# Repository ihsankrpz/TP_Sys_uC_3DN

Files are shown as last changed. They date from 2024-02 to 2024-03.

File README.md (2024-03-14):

# TP_Sys_uC_3DN

This project is an learning project of using STM32L021K4T6 with KiCAD.
There is three part : 
	- Datasheets : All datashetts needed for the project
	- Firmware : STM32 firmware using STM32CubeIDE
	- Hardware : Conception with KiCAD.

# Hardware

#STM32L021K4T6
PB9 pin is connected to reset. L1,C4 and C5 is used to filter power supply.

#POWER SUPPLY
For the power supply, the datasheet indicated that all C's need to be more than 0.47uF.

#DAC
For DAC, in page 25, datasheet of MCP4801 indicates that C9 has to be 100n and C10 10u. 
not(CS) is the Chip Select input pin, which requires an active low to enable serial clock and data functions. 
not(LDAC) (latch DAC synchronization input) pin is used to transfer the input latch register to the DAC register (output latches, VOUT). 
When this pin is low, VOUT is updated with input register content. 
This pin can be tied to low (VSS) if the VOUT update is desired at the rising edge of the CS pin. 
This pin can be driven by an external control device such as an MCU I/O pin. 
MISO pin of SDI not used because STM32 is used Transmit only.

# Firmware

#LL drivers
Using LL drivers instead of using HAL drivers allows to use low-level registers to have beter optimisation.
LL drivers are specific to uC and HAL drivers are more portable.

#__STATIC_INLINE
__STATIC_INLINE is used to declare a function statically and the compiler will generate function only where necessary.

#Led_Timer
We have 32Mhz clock and we need to scale the timer at 1kHz clock. We choose PSC + ARR  = 32000.

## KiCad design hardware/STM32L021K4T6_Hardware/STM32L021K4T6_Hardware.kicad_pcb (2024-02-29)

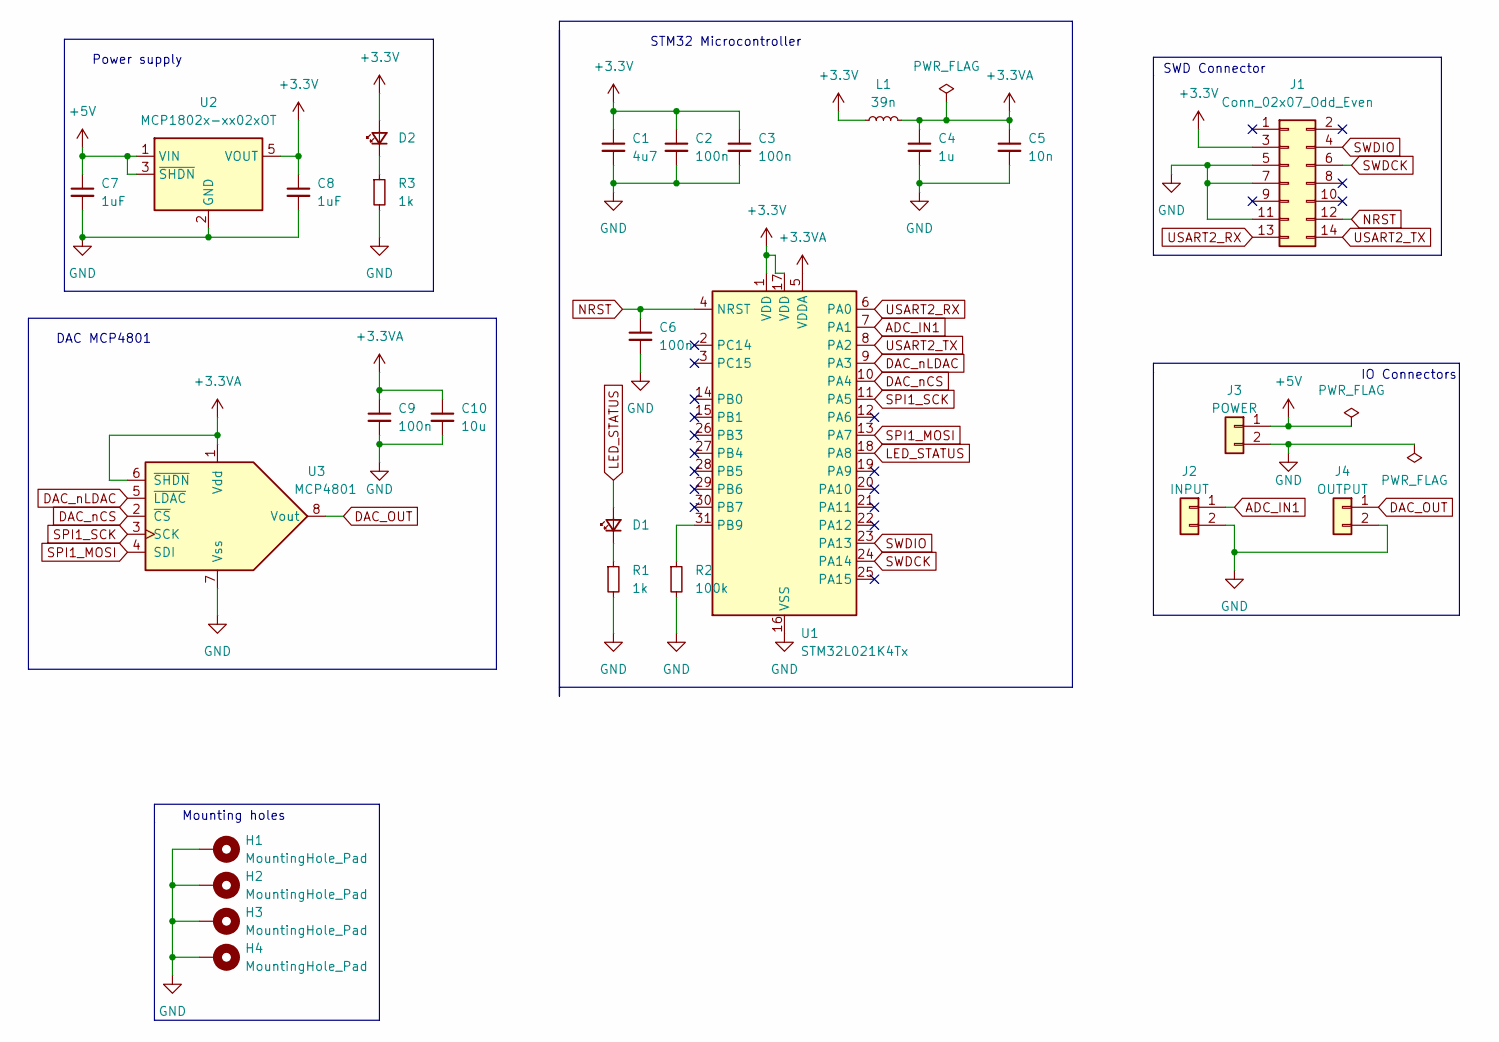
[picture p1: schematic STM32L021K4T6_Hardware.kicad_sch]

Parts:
C1: 4u7; C_0805_2012Metric_Pad1.18x1.45mm_HandSolder
C2, C3, C6, C9: 100n; C_0805_2012Metric_Pad1.18x1.45mm_HandSolder
C4: 1u; C_0805_2012Metric_Pad1.18x1.45mm_HandSolder
C5: 10n; C_0805_2012Metric_Pad1.18x1.45mm_HandSolder
C7, C8: 1uF; C_0805_2012Metric
C10: 10u; C_0805_2012Metric
D1, D2: LED_0603_1608Metric_Pad1.05x0.95mm_HandSolder
H1, H2, H3, H4: MountingHole_Pad; MountingHole_3.2mm_M3_Pad
J1: Conn_02x07_Odd_Even; PinHeader_2x07_P1.27mm_Vertical_SMD
J2: INPUT; JST_XH_B2B-XH-A_1x02_P2.50mm_Vertical
J3: POWER; JST_XH_B2B-XH-A_1x02_P2.50mm_Vertical
J4: OUTPUT; JST_XH_B2B-XH-A_1x02_P2.50mm_Vertical
L1: 39n; L_0805_2012Metric_Pad1.05x1.20mm_HandSolder
R1, R3: 1k; R_0805_2012Metric_Pad1.20x1.40mm_HandSolder
R2: 100k; R_0805_2012Metric_Pad1.20x1.40mm_HandSolder
U1: STM32L021K4Tx; LQFP-32_7x7mm_P0.8mm
U2: MCP1802x-xx02xOT; SOT-23-5
U3: MCP4801; SOIC-8_3.9x4.9mm_P1.27mm

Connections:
+3.3V: C1.1, C2.1, C3.1, C8.1, D2.2 (A), J1.3, L1.1, U1.1 (VDD), U1.17 (VDD), U2.5 (VOUT)
+3.3VA: C4.1, C5.1, C9.1, C10.1, L1.2, U1.5 (VDDA), U3.1 (Vdd), U3.6 (~SHDN)
+5V: C7.1, J3.1, U2.1 (VIN), U2.3 (~SHDN)
ADC_IN1: J2.1, U1.7 (PA1)
DAC_OUT: J4.1, U3.8 (Vout)
DAC_nCS: U1.10 (PA4), U3.2 (~CS)
DAC_nLDAC: U1.9 (PA3), U3.5 (~LDAC)
GND: C1.2, C2.2, C3.2, C4.2, C5.2, C6.2, C7.2, C8.2, C9.2, C10.2, H1.1, H2.1, H3.1, H4.1, J1.5, J1.7, J1.11, J2.2, J3.2, J4.2, R1.2, R2.2, R3.2, U1.16 (VSS), U1.32 (VSS), U2.2 (GND), U3.7 (Vss)
LED_STATUS: D1.2 (A), U1.18 (PA8)
NRST: C6.1, J1.12, U1.4 (NRST)
unnamed: D1.1 (K), R1.1
unnamed: D2.1 (K), R3.1
unnamed: R2.1, U1.31 (PB9)
SPI1_MOSI: U1.13 (PA7), U3.4 (SDI)
SPI1_SCK: U1.11 (PA5), U3.3 (SCK)
SWDCK: J1.6, U1.24 (PA14)
SWDIO: J1.4, U1.23 (PA13)
USART2_RX: J1.13, U1.6 (PA0)
USART2_TX: J1.14, U1.8 (PA2)

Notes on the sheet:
STM32 Microcontroller
IO Connectors
SWD Connector
Power supply
DAC MCP4801
Mounting holes

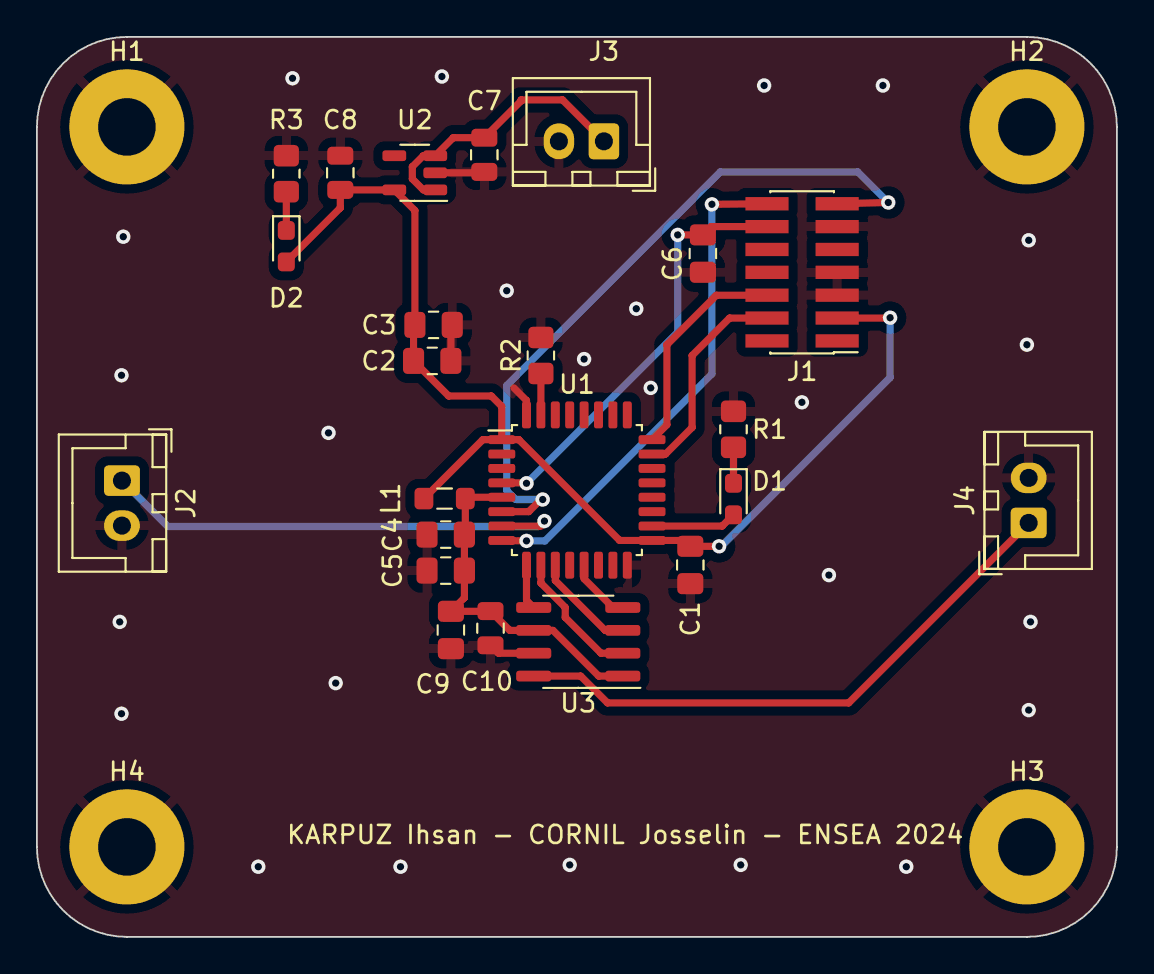
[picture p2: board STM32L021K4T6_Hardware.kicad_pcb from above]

Board: 2 copper layers, 60.0 x 50.0 mm, 27 parts (0 on the bottom side), 19 nets.

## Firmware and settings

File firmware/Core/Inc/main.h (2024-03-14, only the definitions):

#define DAC_nLDAC_Pin LL_GPIO_PIN_3
#define DAC_nLDAC_GPIO_Port GPIOA
#define DAC_nCS_Pin LL_GPIO_PIN_4
#define DAC_nCS_GPIO_Port GPIOA
#define NVIC_PRIORITYGROUP_0         ((uint32_t)0x00000007) /*!< 0 bit  for pre-emption priority,
#define NVIC_PRIORITYGROUP_1         ((uint32_t)0x00000006) /*!< 1 bit  for pre-emption priority,
#define NVIC_PRIORITYGROUP_2         ((uint32_t)0x00000005) /*!< 2 bits for pre-emption priority,
#define NVIC_PRIORITYGROUP_3         ((uint32_t)0x00000004) /*!< 3 bits for pre-emption priority,
#define NVIC_PRIORITYGROUP_4         ((uint32_t)0x00000003) /*!< 4 bits for pre-emption priority,

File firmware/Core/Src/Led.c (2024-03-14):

/*
 * Led.c
 *
 *  Created on: Mar 14, 2024
 *      Author: ihsan
 */
#include "Led.h"

// Variable globale pour stocker la luminosité actuelle de la LED
static uint8_t brightness = 0;

// Démarre le timer
void LedStart(void)
{
	LL_TIM_EnableCounter(TIM2);
	LL_TIM_CC_EnableChannel(TIM2, LL_TIM_CHANNEL_CH1);
}
// Configure le rapport cyclique de la PWM entre 0 et 255
void LedSetValue(uint8_t val)
{
	LL_TIM_OC_SetCompareCH1(TIM2, val);
}
// À chaque appel, cette fonction incrémente la luminosité de la LED
// Arrivé à la valeur maximale, chaque appel décrémente la LED
void LedPulse() {
    static uint8_t direction = 1; // 1 pour incrémenter, -1 pour décrémenter

    // Incrémente ou décrémente la luminosité en fonction de la direction
    brightness += direction;

    // Si la luminosité atteint la valeur maximale, change de direction
//    if (brightness >= TIM2->CNT) {
    if (brightness >= 255) {
        direction = -1; // Change de direction pour décrémenter
    }

    // Si la luminosité atteint 0, change de direction
    if (brightness <= 0) {
        direction = 1; // Change de direction pour incrémenter
    }

    //Activation de la led
    LedSetValue(brightness);
}

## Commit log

2024-02-09 pinout stm32
    [STM32L021K4T6_Hardware.kicad_pcb, STM32L021K4T6_Hardware.kicad_sch]
2024-02-09 schematic and footprints
    [STM32L021K4T6_Hardware.kicad_sch]
2024-02-09 add mounting holes
    [STM32L021K4T6_Hardware.kicad_sch]
2024-02-29 drc check bis
    [STM32L021K4T6_Hardware.kicad_pcb]
2024-02-29 drc check ok bis bis
    [STM32L021K4T6_Hardware.kicad_pcb]
2024-02-29 J3 reversed
    [STM32L021K4T6_Hardware.kicad_pcb]
2024-03-14 led test
2024-03-14 update led test with interrupt

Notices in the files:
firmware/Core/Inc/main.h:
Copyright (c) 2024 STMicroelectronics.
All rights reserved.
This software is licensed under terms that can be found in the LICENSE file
